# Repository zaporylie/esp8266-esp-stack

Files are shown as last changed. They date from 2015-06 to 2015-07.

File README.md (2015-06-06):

# ESP stack

## Goal

Cheap and easy to use (and make it at home) development kit for ESP8266 based projects.

## Available boards

* core, compatible with esp-07 esp-12 and esp-12e
* pl2303 - use it together with external FTDI board

## Contribution

## Licence

This project is licenced under GNU General Public Licence, version 2 or later. You can take it from here, use in free or commercial projects. However, you must distribute it under the GPL version 2 or later, so those you sell it to must be allowed to modify and redistribute it as well.

## Credits

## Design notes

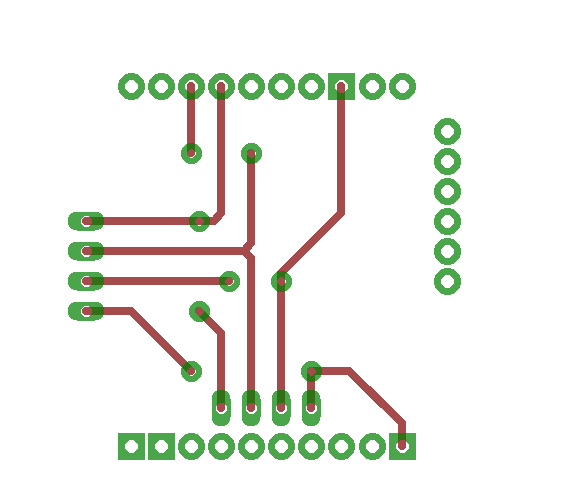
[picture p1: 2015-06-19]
oled/oled.png

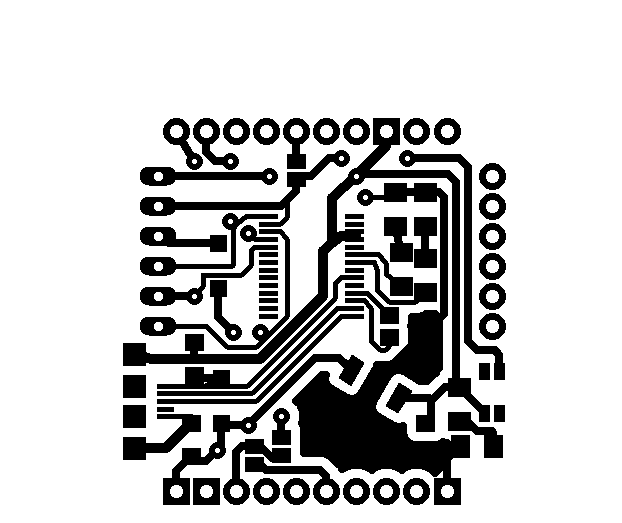
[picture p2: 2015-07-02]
power/power.png

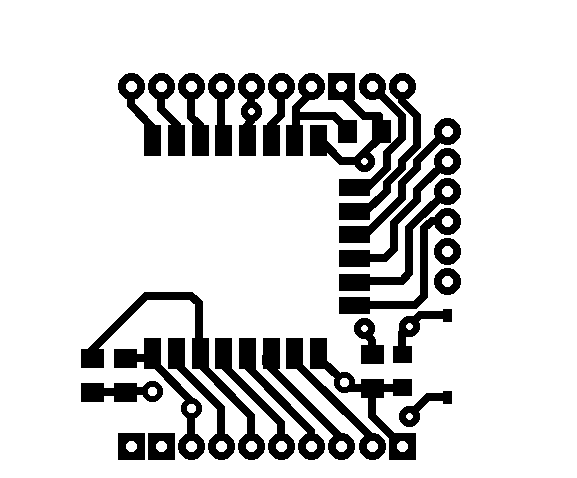
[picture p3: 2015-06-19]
esp-core/esp-core.png

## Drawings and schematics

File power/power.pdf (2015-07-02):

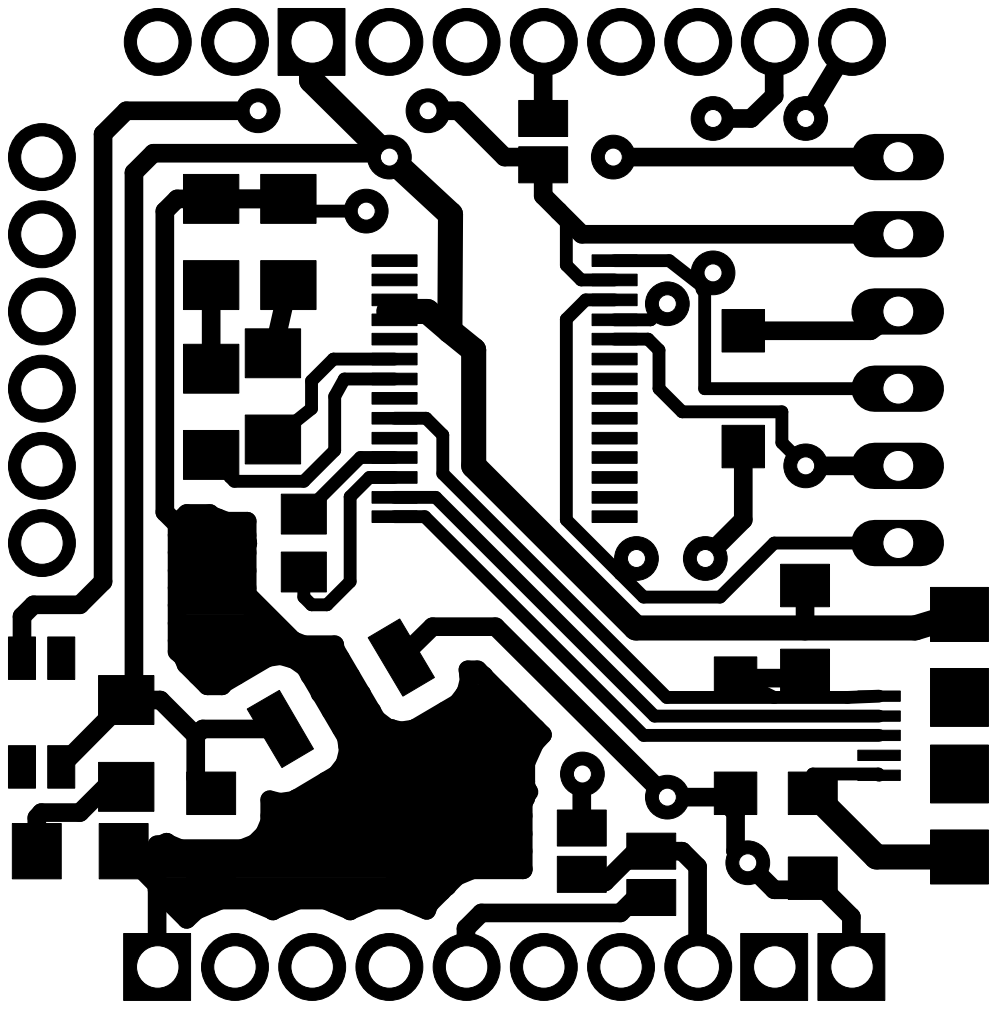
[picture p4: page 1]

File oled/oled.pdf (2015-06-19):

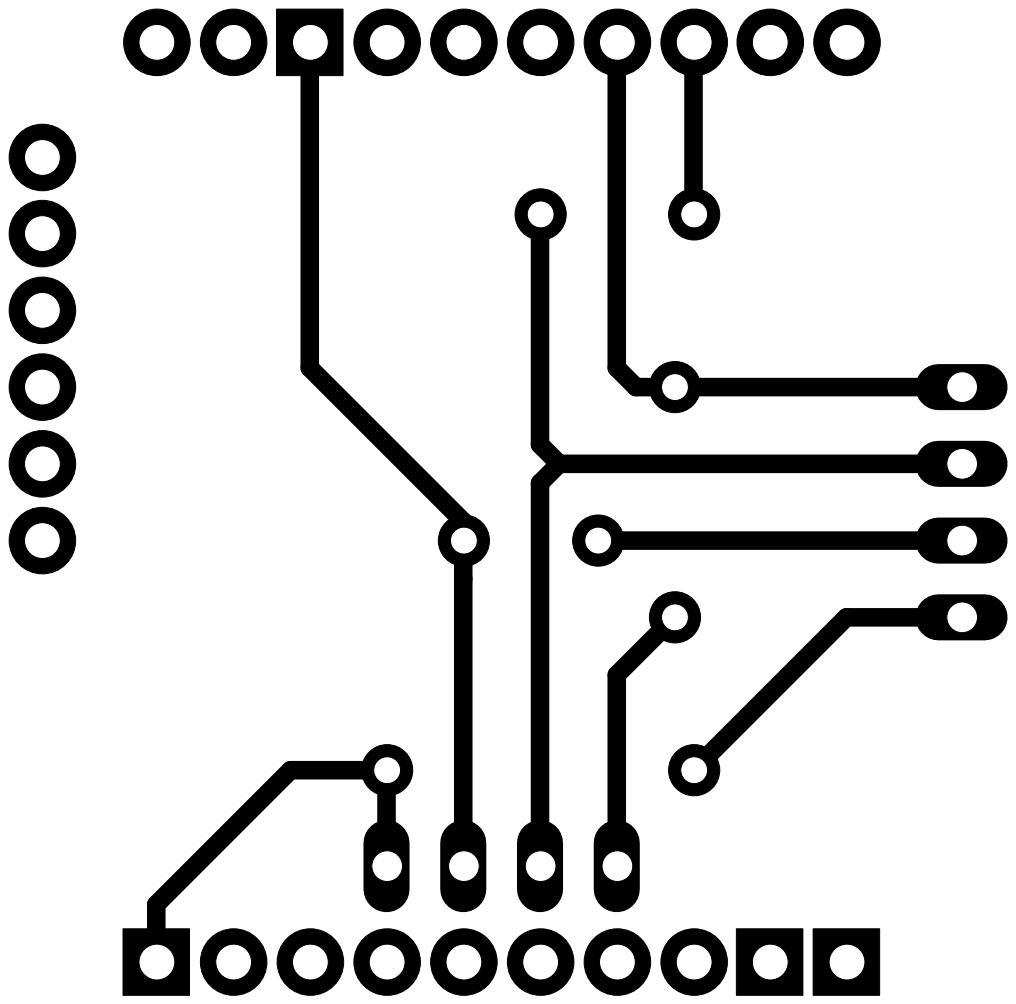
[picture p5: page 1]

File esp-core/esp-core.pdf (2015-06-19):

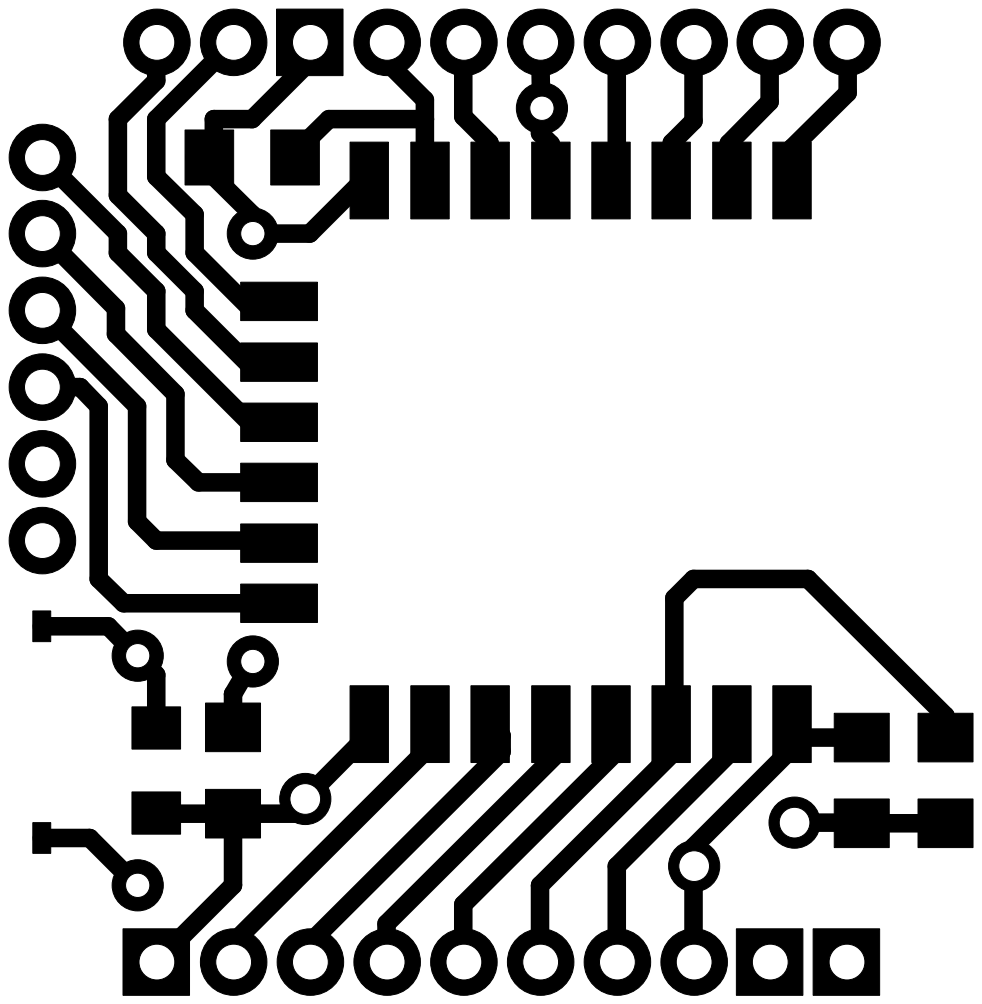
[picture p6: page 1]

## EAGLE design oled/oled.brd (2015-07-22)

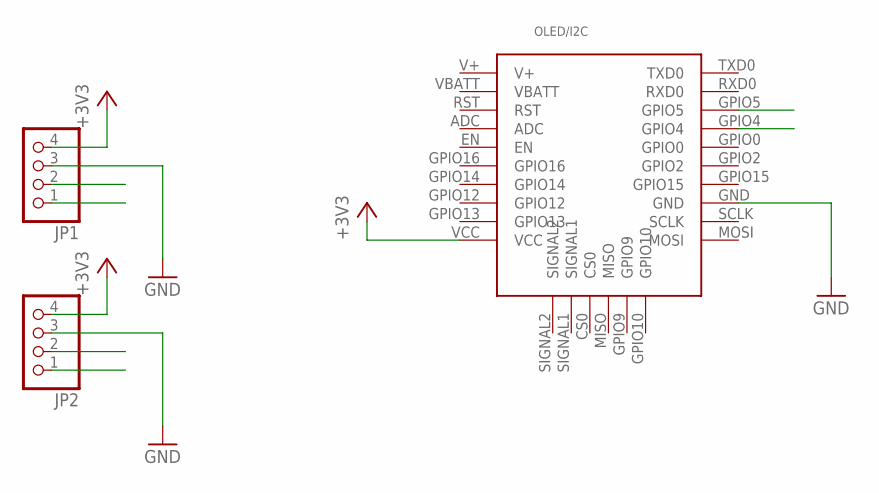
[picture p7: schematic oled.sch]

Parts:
JP1, JP2: PINHD-1X4; 1X04
OLED/I2C: ESP-BOARD

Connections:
+3V3: JP1.4, JP2.4, OLED/I2C.VCC
GND: JP1.3, JP2.3, OLED/I2C.GND
SCL: JP1.2, JP2.2, OLED/I2C.GPIO5
SDA: JP1.1, JP2.1, OLED/I2C.GPIO4
V+: OLED/I2C.V+
VBATT: OLED/I2C.VBATT

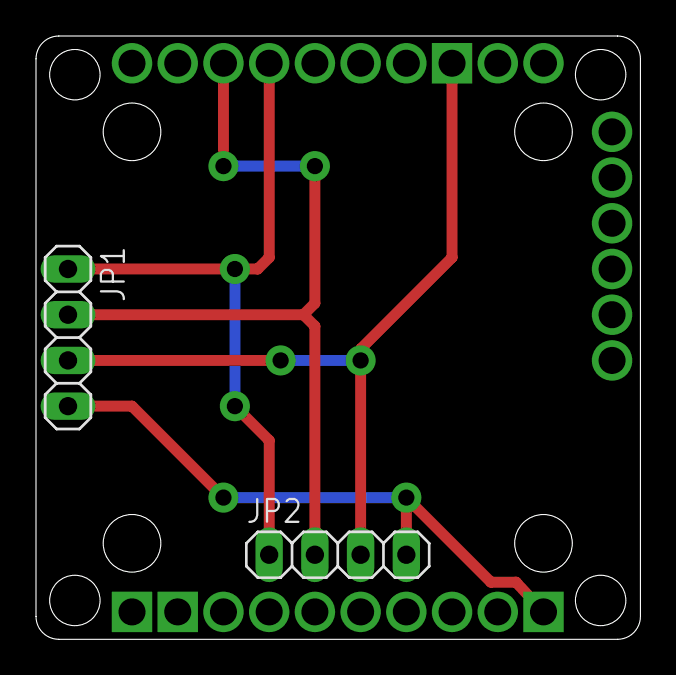
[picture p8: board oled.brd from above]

Board: 2 copper layers, 33.6 x 33.5 mm, 3 parts (0 on the bottom side), 4 nets.

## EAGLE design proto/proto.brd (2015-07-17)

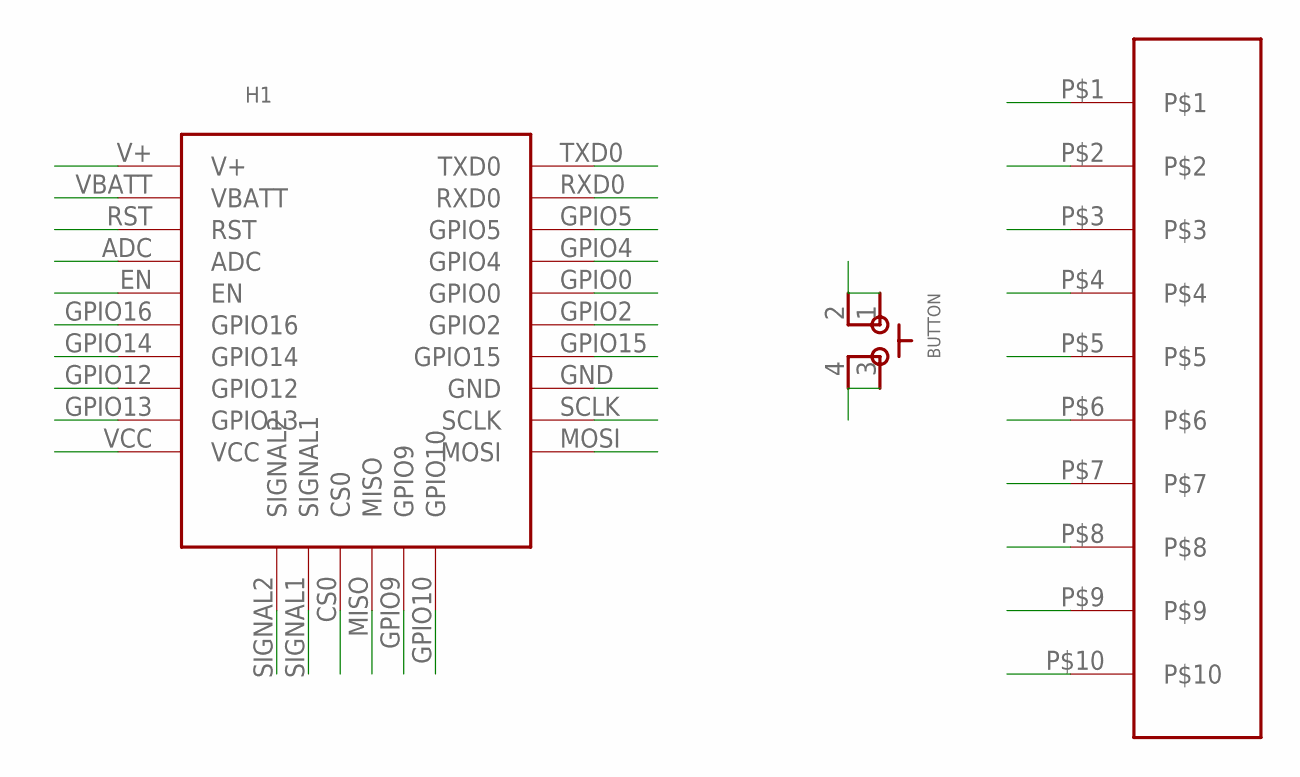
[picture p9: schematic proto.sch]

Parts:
BUTTON: SKSCLDE010
H1: ESP-BOARD
U$1: 1X10-EDGE

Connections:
ADC: H1.ADC
CS0: H1.CS0
EN: H1.EN
GND: H1.GND
GPIO0: H1.GPIO0
GPIO2: H1.GPIO2
GPIO4: H1.GPIO4
GPIO5: H1.GPIO5
GPIO9: H1.GPIO9
GPIO10: H1.GPIO10
GPIO12: H1.GPIO12
GPIO13: H1.GPIO13
GPIO14: H1.GPIO14
GPIO15: H1.GPIO15
GPIO16: H1.GPIO16
MISO: H1.MISO
MOSI: H1.MOSI
P0: U$1.P$10
P1: U$1.P$9
P2: U$1.P$8
P3: U$1.P$7
P4: U$1.P$6
P5: U$1.P$5
P6: U$1.P$4
P7: U$1.P$3
P8: U$1.P$2
P9: U$1.P$1
RST: H1.RST
RXD0: H1.RXD0
SCLK: H1.SCLK
SIGNAL1: H1.SIGNAL1
SIGNAL2: H1.SIGNAL2
SW1: BUTTON.3 (4), BUTTON.4 (3)
SW2: BUTTON.1, BUTTON.2
TXD0: H1.TXD0
V+: H1.V+
VBATT: H1.VBATT
VCC: H1.VCC

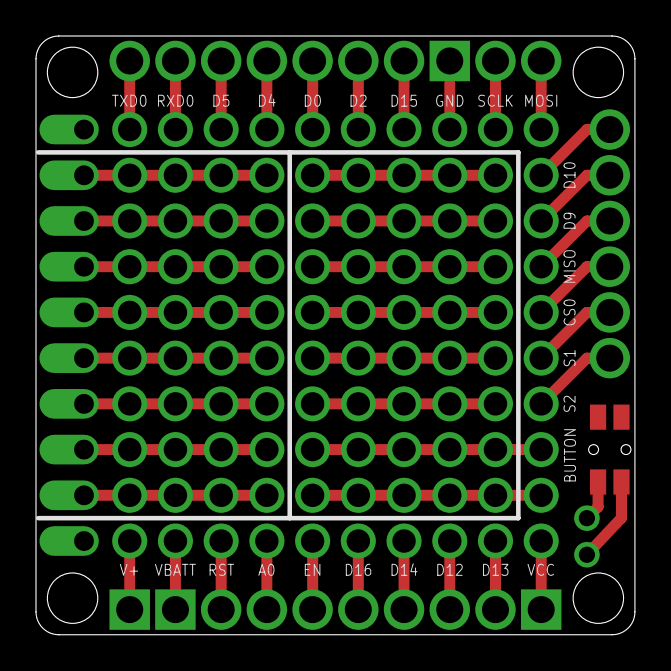
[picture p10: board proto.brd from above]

Board: 2 copper layers, 33.3 x 33.3 mm, 3 parts (0 on the bottom side), 2 nets.

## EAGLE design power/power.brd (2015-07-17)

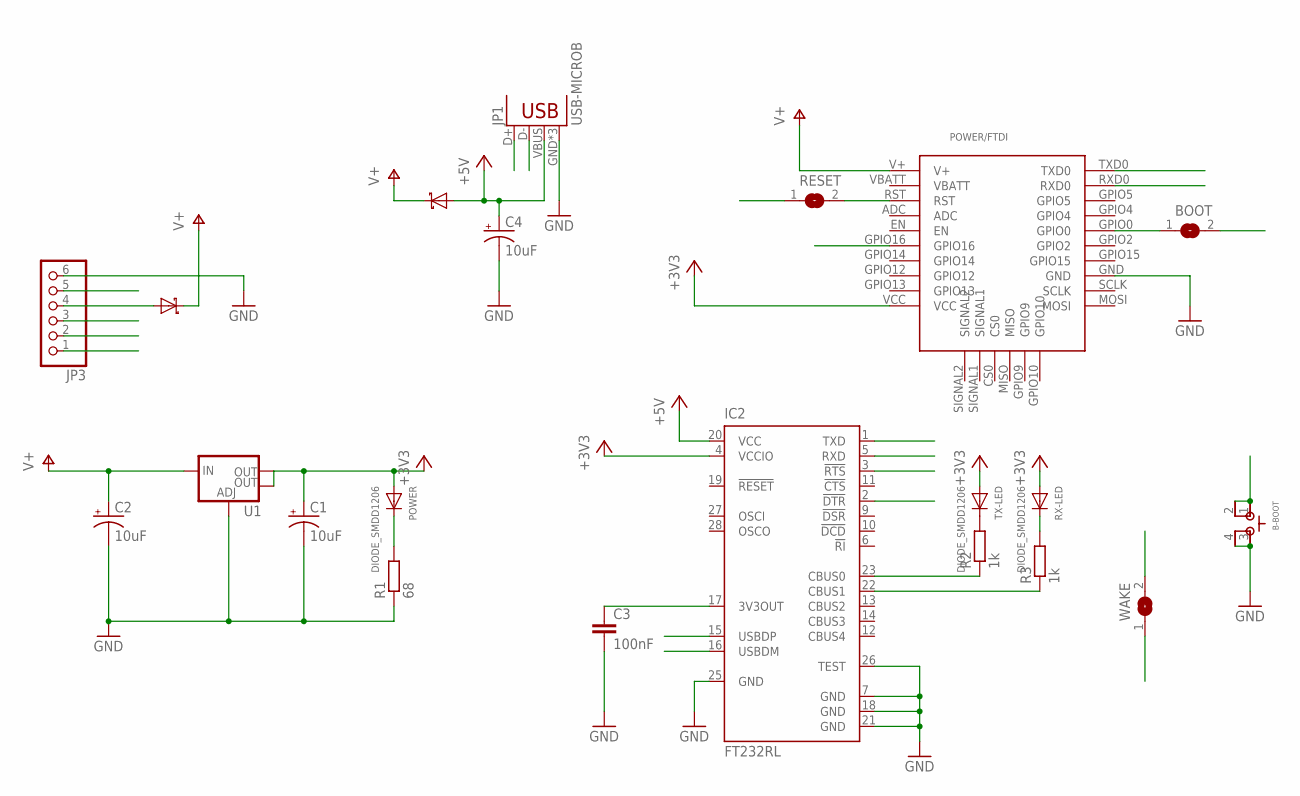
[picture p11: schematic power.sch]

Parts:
B-BOOT: SKSCLDE010
BOOT: SJ
C1, C2, C4: 10uF; EIA3216
C3: 100nF; C0805
D1, D2: MBR120; SOD123
IC2: FT232RL; SSOP28
JP1: USB-MICROB
JP3: PINHD-1X6; 1X06
POWER: DIODE_SMDD1206; D1206
POWER/FTDI: ESP-BOARD
R1: 68; R1206
R2, R3: 1k; R1206
RESET: SJ
RX-LED: DIODE_SMDD1206; D1206
TX-LED: DIODE_SMDD1206; D1206
U1: V_REG_LM1117SOT223; SOT223
WAKE: SJ

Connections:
+3V3: C1.A (+), IC2.4 (VCCIO), POWER.A, POWER/FTDI.VCC, RX-LED.A, TX-LED.A, U1.2 (OUT), U1.4 (OUT)
+5V: C4.A (+), D1.A, IC2.20 (VCC), JP1.VBUS
D+: IC2.15 (USBDP), JP1.D+
D-: IC2.16 (USBDM), JP1.D-
DTR: B-BOOT.1, B-BOOT.2, BOOT.2, IC2.2 (!DTR), JP3.5
GND: B-BOOT.3 (4), B-BOOT.4 (3), C1.C (-), C2.C (-), C3.2, C4.C (-), IC2.7 (GND), IC2.18 (GND), IC2.21 (GND), IC2.25 (GND), IC2.26 (TEST), JP1.GND, JP1.MT1 (GND), JP1.MT2 (GND), JP3.6, POWER/FTDI.GND, R1.1, U1.1 (ADJ)
GPIO0: BOOT.1, POWER/FTDI.GPIO0
GPIO16: POWER/FTDI.GPIO16, WAKE.1
unnamed: POWER.K, R1.2
unnamed: IC2.22 (CBUS1), R3.1
unnamed: R2.2, TX-LED.K
unnamed: IC2.23 (CBUS0), R2.1
unnamed: D2.A, JP3.4
unnamed: R3.2, RX-LED.K
unnamed: C3.1, IC2.17 (3V3OUT)
RST: POWER/FTDI.RST, RESET.2, WAKE.2
RTS: IC2.3 (!RTS), JP3.1, RESET.1
RXD: IC2.5 (RXD), JP3.2, POWER/FTDI.TXD0
TXD: IC2.1 (TXD), JP3.3, POWER/FTDI.RXD0
V+: C2.A (+), D1.C, D2.C, POWER/FTDI.V+, U1.3 (IN)
VBATT: POWER/FTDI.VBATT

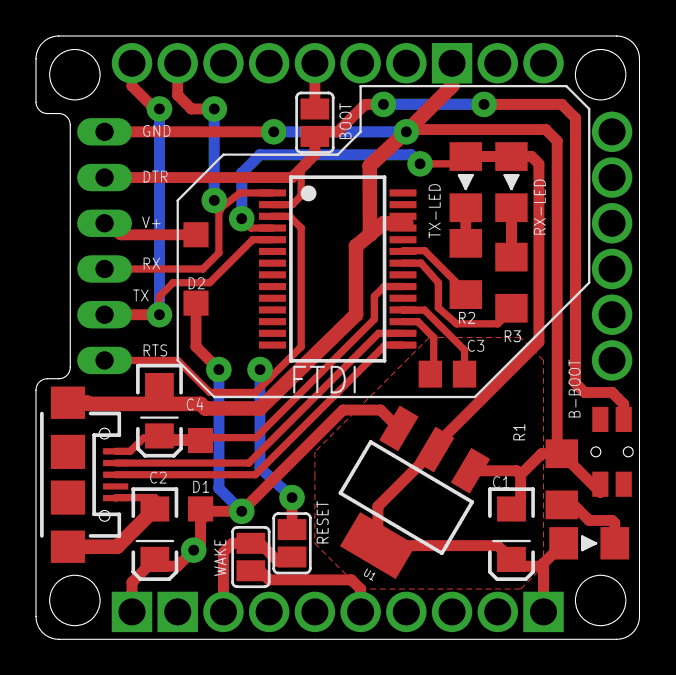
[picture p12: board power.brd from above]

Board: 2 copper layers, 33.5 x 33.5 mm, 21 parts (0 on the bottom side), 20 nets.

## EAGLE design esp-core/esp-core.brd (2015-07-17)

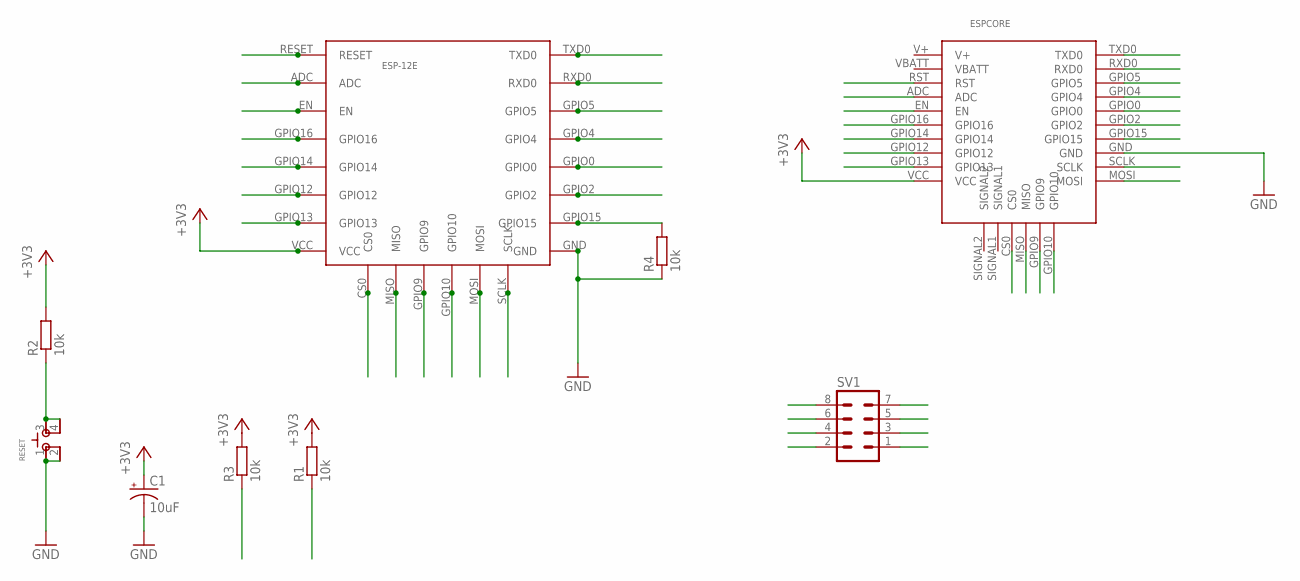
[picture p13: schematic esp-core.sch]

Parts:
C1: 10uF; EIA3216
ESP-12E: ESP-12E
ESPCORE: ESP-BOARD
R1, R2, R3, R4: 10k; R1206
RESET: SKSCLDE010
SV1: MA04-2

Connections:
+3V3: C1.A (+), ESP-12E.VCC, ESPCORE.VCC, R1.2, R2.2, R3.2, SV1.7
ADC: ESP-12E.ADC, ESPCORE.ADC
CS0: ESP-12E.CS0, ESPCORE.CS0
EN: ESP-12E.EN, ESPCORE.EN, R1.1, SV1.3
GND: C1.C (-), ESP-12E.GND, ESPCORE.GND, R4.1, RESET.1, RESET.2, SV1.2
GPIO0: ESP-12E.GPIO0, ESPCORE.GPIO0, R3.1, SV1.6
GPIO2: ESP-12E.GPIO2, ESPCORE.GPIO2, SV1.4
GPIO4: ESP-12E.GPIO4, ESPCORE.GPIO4
GPIO5: ESP-12E.GPIO5, ESPCORE.GPIO5
GPIO9: ESP-12E.GPIO9, ESPCORE.GPIO9
GPIO10: ESP-12E.GPIO10, ESPCORE.GPIO10
GPIO12: ESP-12E.GPIO12, ESPCORE.GPIO12
GPIO13: ESP-12E.GPIO13, ESPCORE.GPIO13
GPIO14: ESP-12E.GPIO14, ESPCORE.GPIO14
GPIO15: ESP-12E.GPIO15, ESPCORE.GPIO15, R4.2
GPIO16: ESP-12E.GPIO16, ESPCORE.GPIO16
MISO: ESP-12E.MISO, ESPCORE.MISO
MOSI: ESP-12E.MOSI, ESPCORE.MOSI
RESET: ESP-12E.RESET, ESPCORE.RST, R2.1, RESET.3 (4), RESET.4 (3), SV1.5
RXD0: ESP-12E.RXD0, ESPCORE.RXD0, SV1.8
SCLK: ESP-12E.SCLK, ESPCORE.SCLK
TXD0: ESP-12E.TXD0, ESPCORE.TXD0, SV1.1
V+: ESPCORE.V+
VBATT: ESPCORE.VBATT

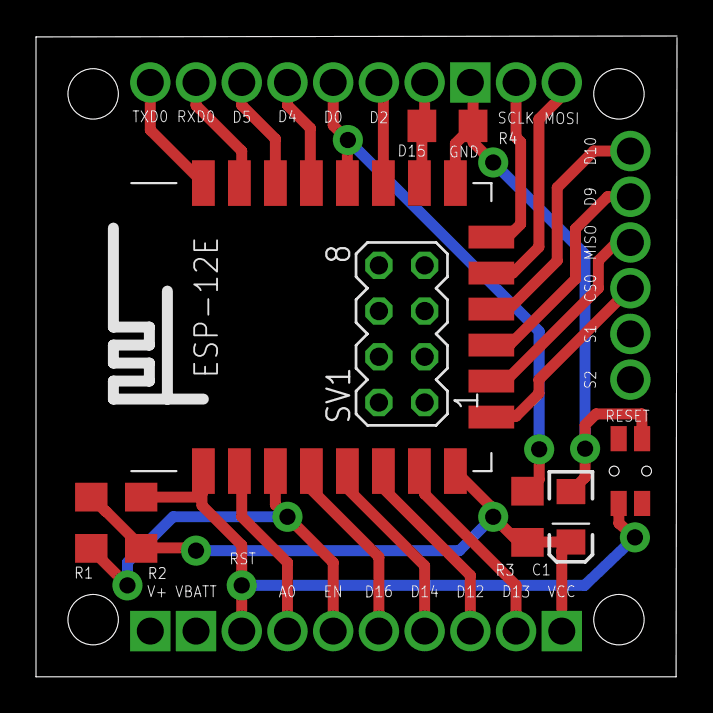
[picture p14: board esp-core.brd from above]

Board: 2 copper layers, 35.6 x 35.6 mm, 10 parts (0 on the bottom side), 22 nets.

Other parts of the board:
U$1: OSHW2

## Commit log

2015-06-06 Core board, compatibile with esp-07, esp-12, esp-12e
    [esp-07:12:12e.brd, esp-07:12:12e.sch]
2015-06-06 Added capacitor for power stability
    [esp-07:12:12e.brd, esp-07:12:12e.sch]
2015-06-07 Add power board - micro USB, LDO 3.3V, capacitors and status LED + spare input header
    [power.brd, power.sch]
2015-06-08 Fix paths under ESP board - shouldn't overlap with module pads
    [esp-07:12:12e.brd]
2015-06-14 New board size - 1.4 inches; reduced number of signal pins to only two; mounting holes
    [esp-07:12:12e.brd, esp-07:12:12e.sch]
2015-06-14 FTDI board update - new board size and mounting holes
    [pl2303.brd, pl2303.sch]
2015-06-14 Small clearance improvements, bigger header pads and mounting holes
    [esp-07:12:12e.brd, esp-07:12:12e.sch, pl2303.brd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]
2015-06-16 Modify ESP library - add ESP module component
    [esp-07:12:12e.brd, esp-07:12:12e.sch]
2015-06-16 New version of esp-core board
    [esp-core.brd, esp-core.sch]
2015-06-17 New board schema applied to ftdi module
    [pl2303.brd, pl2303.sch]
2015-06-19 Add pull-up and down resistors to 'special' pins - GPIO0 and GPIO15
    [esp-core.brd, esp-core.sch]
2015-06-19 OLED/i2c board
    [oled.brd, oled.sch]
2015-06-20 Removed unused device from library, change drill size.
2015-06-21 Fix small DRC issues with esp-core board
    [esp-core.brd, esp-core.sch]
2015-06-22 Add new part to library - tact switch
2015-06-22 Fix button on board
    [esp-core.brd, esp-core.sch]
2015-06-23 Add openhardware icon to library and to core board
    [esp-core.brd, esp-core.sch]
2015-07-01 esp-core v0.1
    [esp-core.brd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]
2015-07-01 Power/FTDI board
    [power.brd, power.sch]
2015-07-02 Power board (USB, external power, FT232RL section
    [power.brd, power.sch]
2015-07-02 Removed pl2303 since power board will cover this part
    [pl2303.brd, pl2303.sch]
2015-07-16 Small improvements to usb board
    [power.brd, power.sch]
2015-07-16 proto board
    [proto.GBL, proto.GBO, proto.GBP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]
2015-07-16 core board fixes
    [esp-core.brd, esp-core.sch]
2015-07-17 Unify all boards, buttons in the same place, board dimension reduced to 1.32inch
    [esp-core.brd, esp-core.sch, power.brd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]
2015-07-22 Improve oled board
    [oled.brd, oled.sch]

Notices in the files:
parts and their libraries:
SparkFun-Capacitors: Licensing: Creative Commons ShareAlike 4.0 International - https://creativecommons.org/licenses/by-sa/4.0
